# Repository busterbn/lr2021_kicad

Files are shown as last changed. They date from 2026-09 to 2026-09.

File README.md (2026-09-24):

# LR2021 868/915 MHz eval module in KiCad

KiCad 10 port of Semtech's LR2021 reference design, the 868/915 MHz evaluation module (e788v01a), converted from the original Altium project.

- `e788v01a/` KiCad project (schematic, board, design rules, symbol and footprint libraries with 3D models)
- `tools/` scripts used for the conversion

Open `e788v01a/LR2021_e788v01a_868_915_eval_module.kicad_pro` in KiCad 10 or newer.

## Verification

- Schematic and PCB connectivity match pin by pin (`tools/check.sh`). The Altium board was used as the reference.
- The board's 107 nets match the Altium PcbDoc, and footprint placement matches Semtech's pick and place file.
- Gerbers plotted from KiCad match Semtech's production Gerbers on all copper, solder mask and paste layers (`tools/gerber_diff.py`). Drill holes match in count and size.

## Notes

- Update PCB from Schematic shows no changes.
- KiCad treats references without a trailing number as unannotated, so 17 Altium designators got a "1" appended (`J7_SWD` is `J7_SWD1`, `868M` is `868M1`, `ANT_HF` is `ANT_HF1`). On the board, their reference fields are hidden and the original names are plain footprint texts at the same place, so the silkscreen is unchanged. If you rename one of these parts, edit that text too.
- The accessories sheet is a sub-sheet of the main sheet. The Altium project was flat, so labels shared by both sheets are global labels.
- `ANT_HF1` and `ANT_LF1` use a 3-pin symbol (1 signal, 2 and 3 GND). The original SMA footprint had pads 1, 2, 2; the second GND pad is now pad 3. The copper is unchanged.
- The Altium logo symbols had a hidden zero-length dummy pin without a pad. It is removed.
- Semtech's Altium design rules are in the `.kicad_pro` board setup, the netclasses and `.kicad_dru`. The RF clearance rules used Altium's auto-generated net names (`NetL*`, `NetC*`, `NetA*`). These nets are in the `RF` netclass.
- 42 vias under U1 and next to the XIAO module are not tented on the bottom side, as in the original.
- DRC still shows warnings that come from the original design: solder mask openings on Q1 that bridge nets, a small VBAT_3V3 copper island on the bottom layer, silkscreen overlaps and a few dangling track stubs.
- ERC shows off-grid warnings (Altium grid) and "power input not driven" errors from Altium pin types.
- `kicad-cli pcb drc --schematic-parity` reports "No corresponding pin" for nets without labels. This looks like a CLI issue.

## Conversion

1. KiCad: File > Import Non-KiCad Project > Altium Project, then save the schematic.
2. `make_hierarchy.py`: turns the two top-level sheets into root sheet plus sub-sheet.
3. `fix_labels.py`, `annotate_power.py`, `fix_pads.py`, `relink.py`, `netmap.py`, `fplib.py`, `export_fps.py`, `rules.py`, `fix_tenting.py`, `fix_refs.py` (then `relink.py`, `netmap.py` and `rules.py` again, since auto-generated net names follow the references), `fix_nopads.py`.
4. KiCad: Update PCB from Schematic, which only adds KiCad 10 footprint metadata and nets for unused pins.
5. After each step, `check.sh` compares schematic and PCB connectivity.

The KiCad Python scripts (`fix_pads.py`, `export_fps.py`, `fix_refs.py`, `fix_nopads.py`) run with KiCad's bundled Python. `fix_tenting.py` and `gerber_diff.py` need `olefile`, `gerbonara`, `pillow` and `numpy`.

## License

The design is Semtech's. Semtech's download contains no license terms, so ask Semtech before you publish or redistribute it. This is not an official Semtech release.

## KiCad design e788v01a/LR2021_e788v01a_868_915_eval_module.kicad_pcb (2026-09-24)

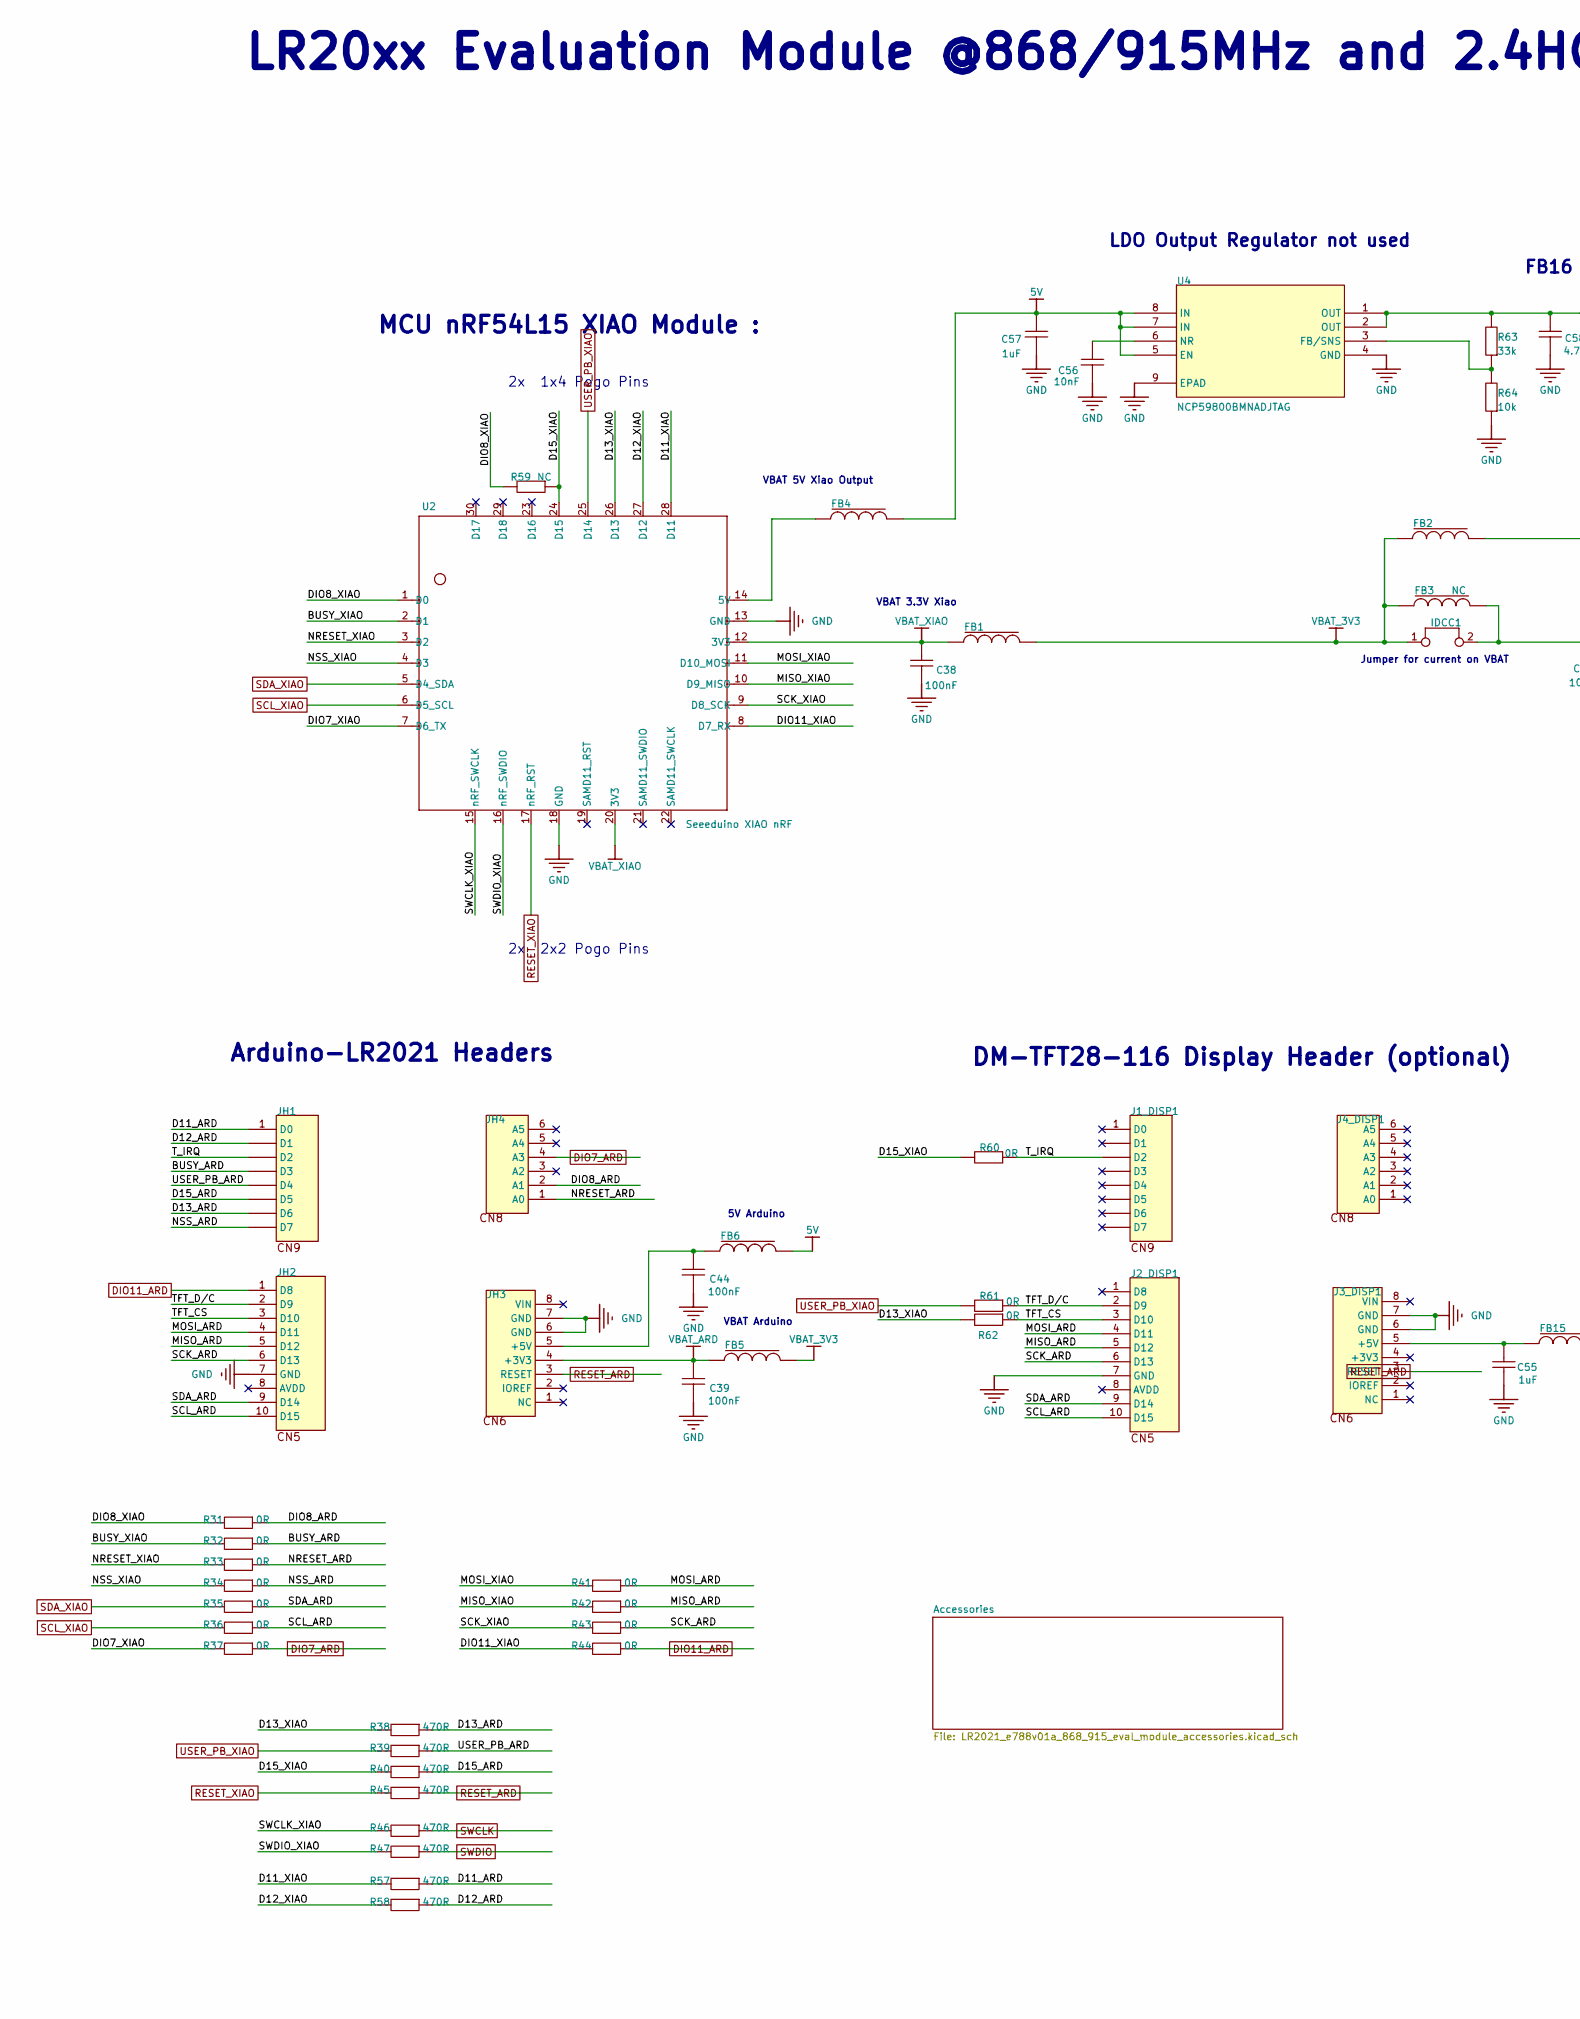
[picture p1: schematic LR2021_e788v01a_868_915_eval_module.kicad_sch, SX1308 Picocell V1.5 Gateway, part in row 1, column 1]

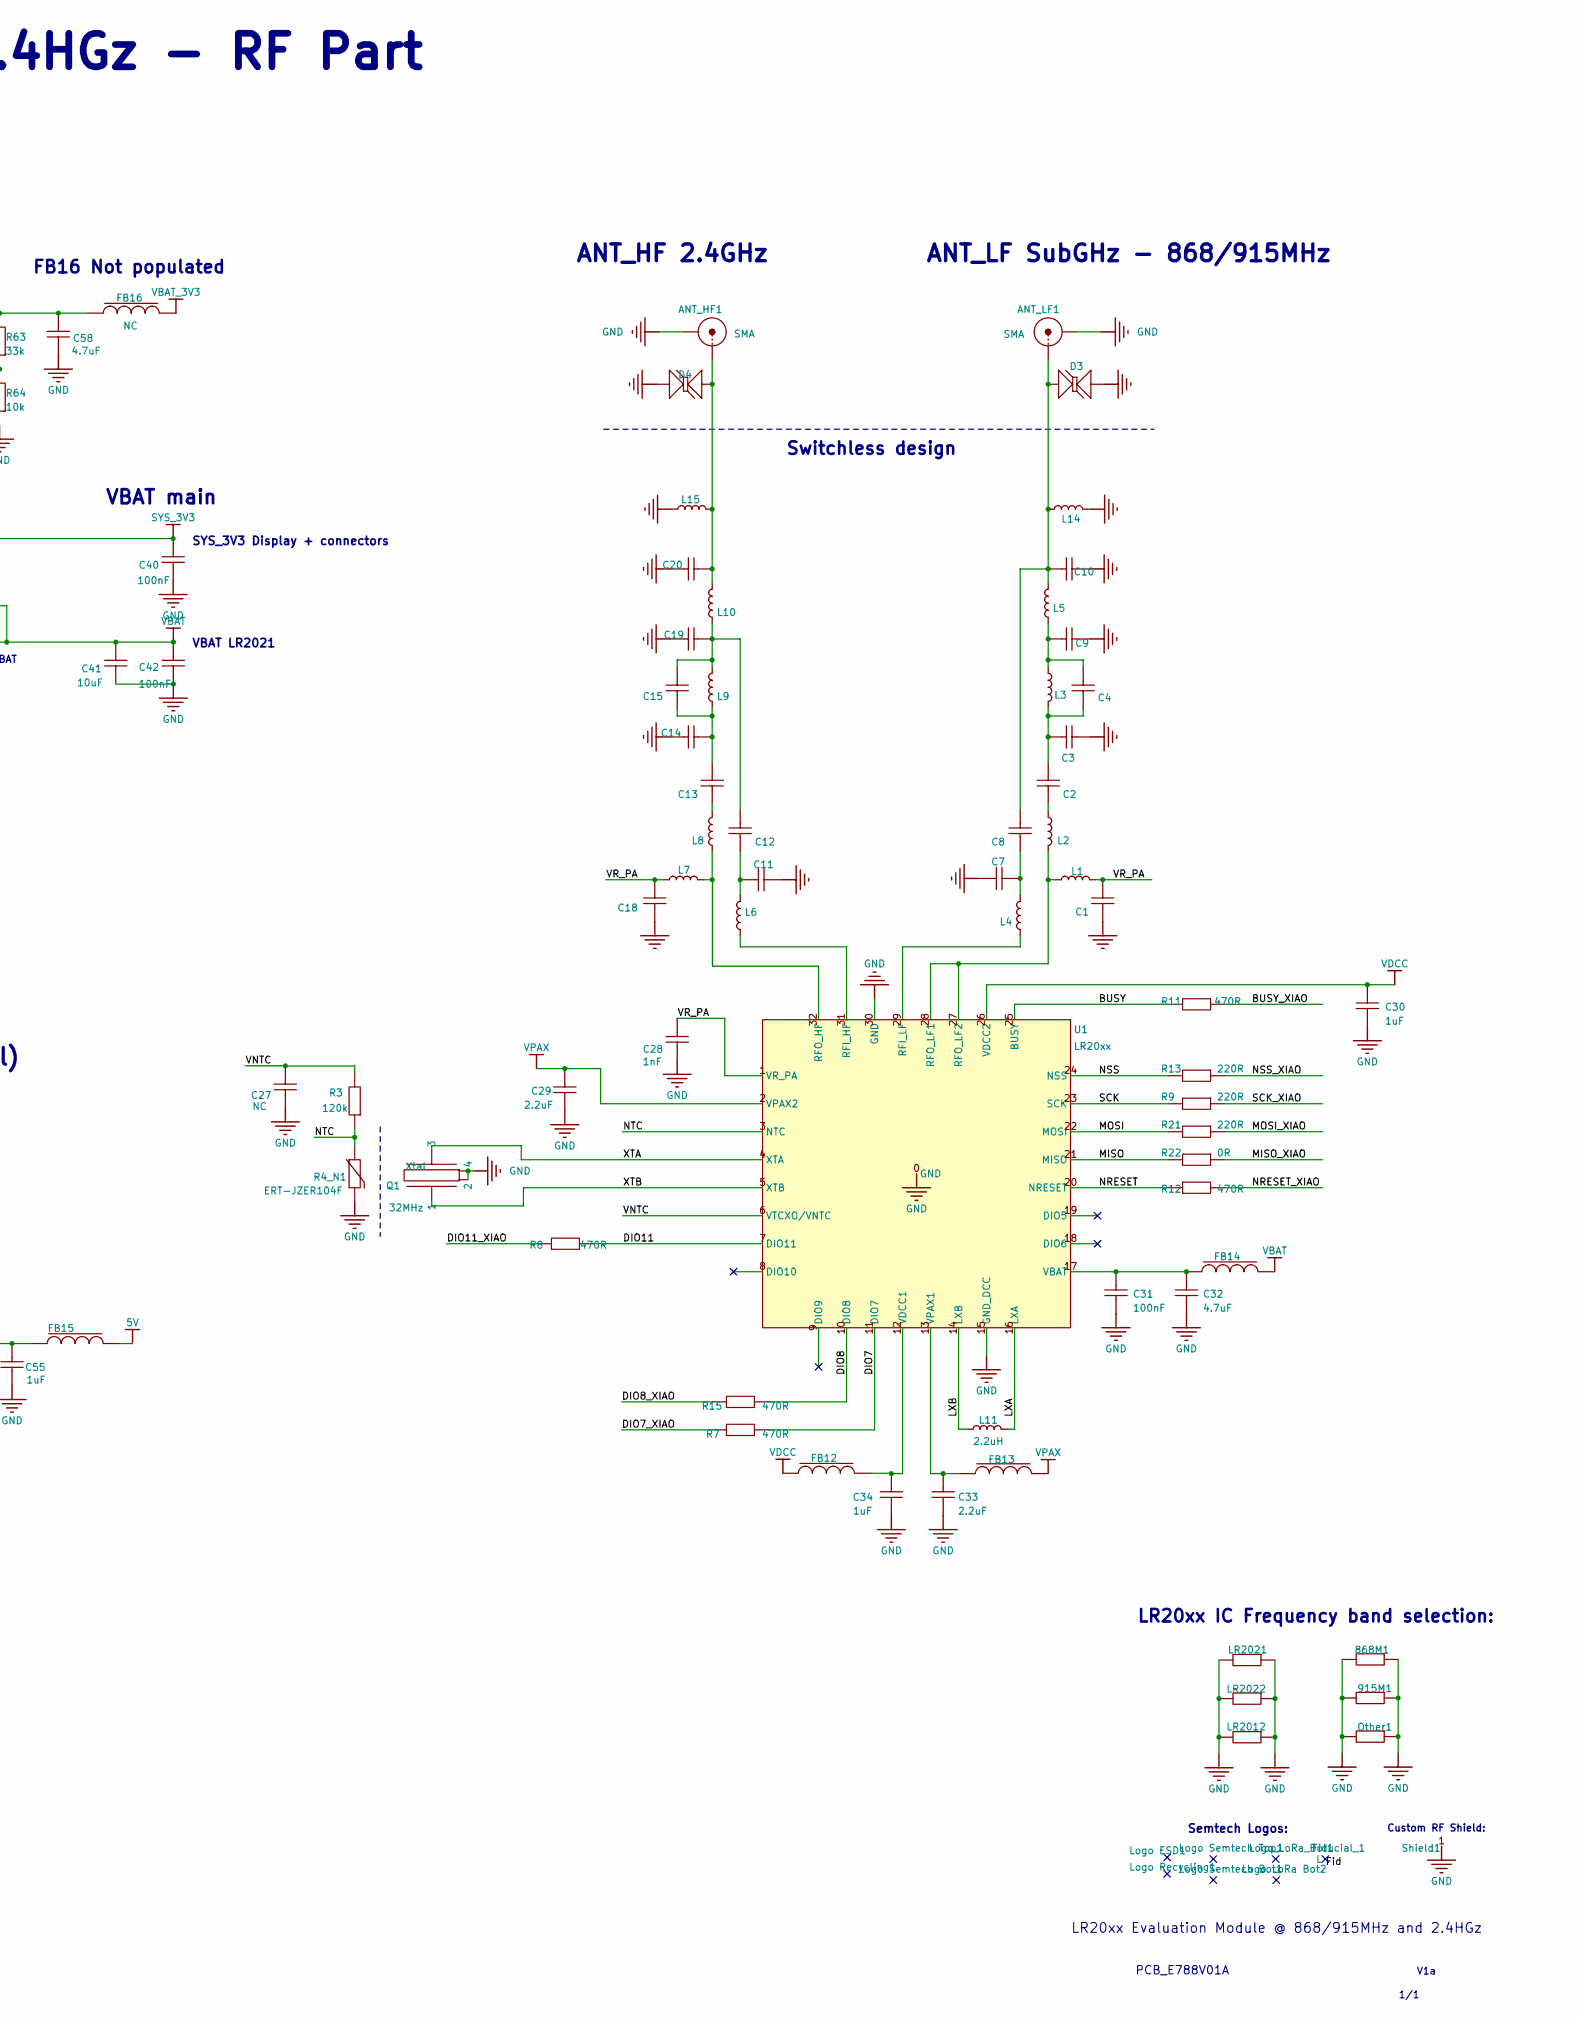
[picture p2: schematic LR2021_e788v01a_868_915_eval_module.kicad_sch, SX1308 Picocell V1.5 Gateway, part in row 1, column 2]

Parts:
868M1, 915M1: Resistor; r_201_smd
ANT_HF1: SMA; SMA_end_launch_1.2mm_6.35mm_female
ANT_LF1: SMA; SMA_end_launch_1.2mm_6.35mm_female
C1, C2, C3, C4, C7, C8, C9, C10, C11, C12, C13, C14, C15, C18, C19, C20, C27, C28, C31, C38, C39, C42, C44, C56: Cap; c_201_smd
C29, C30, C32, C33, C34, C40, C41, C55, C57, C58: Cap; c_402_smd
D3, D4: TVS Diode; SLP0603P2X3F
FB1, FB2, FB3, FB4, FB5, FB6, FB15, FB16: Ferrite beads; Ferrite_402_smd
FB12, FB13, FB14: Ferrite beads; Ferrite_201_smd
Fiducial_1: Fiducial_Mark; fiducial_mark_signal_top Small
IDCC1: Jumper; bridge_254mm
J1_DISP1, J3_DISP1: Header 8; HDR1X8
J2_DISP1: Header 10; HDR1X10
J4_DISP1: Header 6; HDR1X6
JH1: Header 8; HDR1X8 Arduino CN9
JH2: Header 10; HDR1X10 Arduino CN5
JH3: Header 8; HDR1X8 Arduino CN6
JH4: Header 6; HDR1X6 Arduino CN8
L1: Inductor symbol; lqw_402_smd
L2, L3, L5, L6, L7, L8, L9, L10, L14, L15: Inductor symbol; LQW_201_smd
L4: Inductor symbol; LQP_201_smd
L11: Inductor symbol; LQM18P_603_INDUCTOR_SMD
LR2012, LR2021, LR2022: Resistor; r_201_smd
Logo ESD1: Logo symbol; Logo ESD
Logo LoRa Bot2: Logo symbol; Logo LoRa Size4
Logo Recycling1: Logo symbol; Logo Recycling1
Logo Semtech Bot1: Logo symbol; logo_semtech_horiz_size4
Logo Semtech Top1: Logo symbol; logo_semtech_horiz_size3
Logo_LoRa_Bot1: Logo symbol; Logo LoRa Size4
Other1: Resistor; r_201_smd
Q1: Xtal; XTAL_1612
R3, R7, R8, R9, R11, R12, R13, R15, R21, R22, R31, R32, R33, R34, R35, R36, R37, R38, R39, R40, R41, R42, R43, R44, R45, R46, R47, R57, R58, R59, R60, R61, R62, R63, R64: Resistor; r_201_smd
R4_N1: NTC; r_201_smd
Shield1: RF Shield; Custom shield RD LR2021
U1: LR20xx; qfn32l_5x5mm
U2: Seeeduino XIAO nRF; MODULE14P-2.54-21X17.8MM-TEST_nRF54L15
U4: NCP59800BMNADJTAG; DFN8_3X3-0P65_506DB-A_OSI; MANUFACTURER_PART_NUMBER NCP59800BMNADJTAG

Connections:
5V: C57.2, FB4.2, FB6.2, FB15.2, U4.5 (EN), U4.7 (IN), U4.8 (IN); also elsewhere on the board
/BUSY: R11.1, U1.25 (BUSY)
/BUSY_ARD: JH1.4 (D3), R32.2
/BUSY_XIAO: R11.2, R32.1, U2.2 (D1)
/D11_ARD: JH1.1 (D0), R57.2
/D11_XIAO: R57.1, U2.28 (D11)
/D12_ARD: JH1.2 (D1), R58.2
/D12_XIAO: R58.1, U2.27 (D12)
/D13_ARD: JH1.7 (D6), R38.2
/D13_XIAO: R38.1, R62.1, U2.26 (D13)
/D15_ARD: JH1.6 (D5), R40.2
/D15_XIAO: R40.1, R59.2, R60.1, U2.24 (D15)
/DIO7: R7.1, U1.11 (DIO7)
/DIO7_XIAO: R7.2, R37.1, U2.7 (D6_TX)
/DIO8: R15.1, U1.10 (DIO8)
/DIO8_ARD: JH4.2 (A1), R31.2
/DIO8_XIAO: R15.2, R31.1, R59.1, U2.1 (D0)
/DIO11: R8.1, U1.7 (DIO11)
/DIO11_XIAO: R8.2, R44.1, U2.8 (D7_RX)
/Fid: Fiducial_1.0 (L_0)
/LXA: L11.2, U1.16 (LXA)
/LXB: L11.1, U1.14 (LXB)
/MISO: R22.1, U1.21 (MISO)
/MISO_ARD: J2_DISP1.5 (D12), JH2.5 (D12), R42.2
/MISO_XIAO: R22.2, R42.1, U2.10 (D9_MISO)
/MOSI: R21.1, U1.22 (MOSI)
/MOSI_ARD: J2_DISP1.4 (D11), JH2.4 (D11), R41.2
/MOSI_XIAO: R21.2, R41.1, U2.11 (D10_MOSI)
/NRESET: R12.2, U1.20 (NRESET)
/NRESET_ARD: JH4.1 (A0), R33.2
/NRESET_XIAO: R12.1, R33.1, U2.3 (D2)
/NSS: R13.1, U1.24 (NSS)
/NSS_ARD: JH1.8 (D7), R34.2
/NSS_XIAO: R13.2, R34.1, U2.4 (D3)
/NTC: R3.2, R4_N1.2, U1.3 (NTC)
/SCK: R9.1, U1.23 (SCK)
/SCK_ARD: J2_DISP1.6 (D13), JH2.6 (D13), R43.2
/SCK_XIAO: R9.2, R43.1, U2.9 (D8_SCK)
/SCL_ARD: J2_DISP1.10 (D15), JH2.10 (D15), R36.2
/SDA_ARD: J2_DISP1.9 (D14), JH2.9 (D14), R35.2
/SWCLK_XIAO: R46.1, U2.15 (nRF_SWCLK)
/SWDIO_XIAO: R47.1, U2.16 (nRF_SWDIO)
/TFT_CS: J2_DISP1.3 (D10), JH2.3 (D10), R62.2
/TFT_D/C: J2_DISP1.2 (D9), JH2.2 (D9), R61.2
/T_IRQ: J1_DISP1.3 (D2_3), JH1.3 (D2), R60.2
/USER_PB_ARD: JH1.5 (D4), R39.2
/VNTC: C27.2, R3.1, U1.6 (VTCXO/VNTC)
/VR_PA: C1.2, C18.2, C28.2, L1.1, L7.1, U1.1 (VR_PA)
/XTA: Q1.3, U1.4 (XTA)
/XTB: Q1.1, U1.5 (XTB)
DIO7_ARD: JH4.4 (A3), R37.2; also elsewhere on the board
DIO11_ARD: JH2.1 (D8), R44.2; also elsewhere on the board
GND: 868M1.1, 868M1.2, 915M1.1, 915M1.2, ANT_HF1.2 (GND), ANT_HF1.3 (GND), ANT_LF1.2 (GND), ANT_LF1.3 (GND), C1.1, C3.1, C7.1, C9.1, C10.1, C11.1, C14.1, C18.1, C19.1, C20.1, C27.1, C28.1, C29.1, C30.1, C31.1, C32.1, C33.1, C34.1, C38.1, C39.1, C40.1, C41.1, C42.1, C44.1, C55.1, C56.1, C57.1, C58.1, D3.1 (A), D4.1 (A), J2_DISP1.7 (GND), J3_DISP1.6 (GND), J3_DISP1.7 (GND), JH2.7 (GND), JH3.6 (GND), JH3.7 (GND), L14.2, L15.1, LR2012.1, LR2012.2, LR2021.1, LR2021.2, LR2022.1, LR2022.2, Other1.1, Other1.2, Q1.2, Q1.4, R4_N1.1, R64.2, Shield1.1 (1_1), U1.0 (GND), U1.15 (GND_DCC), U1.30 (GND), U2.13 (GND), U2.18 (GND), U4.4 (GND), U4.9 (EPAD); also elsewhere on the board
unnamed: ANT_HF1.1 (Signal), C20.2, D4.2 (K), L10.2, L15.2
unnamed: ANT_LF1.1 (Signal), C8.2, C10.2, D3.2 (K), L5.2, L14.1
unnamed: C2.1, L2.2
unnamed: C2.2, C3.2, C4.1, L3.1
unnamed: C4.2, C9.2, L3.2, L5.1
unnamed: C7.2, C8.1, L4.2
unnamed: C11.2, C12.1, L6.1
unnamed: C12.2, C15.2, C19.2, L9.2, L10.1
unnamed: C13.1, L8.2
unnamed: C13.2, C14.2, C15.1, L9.1
unnamed: C58.2, FB16.1, R63.1, U4.1 (OUT), U4.2 (OUT)
unnamed: C55.2, FB15.1, J3_DISP1.5 (+5V)
unnamed: C44.2, FB6.1, JH3.5 (+5V)
unnamed: L6.2, U1.31 (RFI_HF)
unnamed: L4.1, U1.29 (RFI_LF)
unnamed: L7.2, L8.1, U1.32 (RFO_HF)
unnamed: L1.2, L2.1, U1.27 (RFO_LF2), U1.28 (RFO_LF1)
unnamed: C31.2, C32.2, FB14.1, U1.17 (VBAT)
unnamed: C34.2, FB12.2, U1.12 (VDCC1)
unnamed: C33.2, FB13.1, U1.13 (VPAX1)
unnamed: FB4.1, U2.14 (5V)
unnamed: R63.2, R64.1, U4.3 (FB/SNS)
unnamed: C56.2, U4.6 (NR)
RESET_ARD: J3_DISP1.3 (RESET), JH3.3 (RESET), R45.2; also elsewhere on the board
RESET_XIAO: R45.1, U2.17 (nRF_RST); also elsewhere on the board
SCL_XIAO: R36.1, U2.6 (D5_SCL); also elsewhere on the board
SDA_XIAO: R35.1, U2.5 (D4_SDA); also elsewhere on the board
SWCLK: R46.2; also elsewhere on the board
SWDIO: R47.2; also elsewhere on the board
SYS_3V3: C40.2, FB2.2; also elsewhere on the board
USER_PB_XIAO: R39.1, R61.1, U2.25 (D14); also elsewhere on the board
VBAT: C41.2, C42.2, FB3.2, FB14.2, IDCC1.2
VBAT_3V3: FB1.2, FB2.1, FB3.1, FB5.2, FB16.2, IDCC1.1
VBAT_ARD: C39.2, FB5.1, JH3.4 (+3V3)
VBAT_XIAO: C38.2, FB1.1, U2.12 (3V3), U2.20 (3V3)
VDCC: C30.2, FB12.1, U1.26 (VDCC2)
VPAX: C29.2, FB13.2, U1.2 (VPAX2)

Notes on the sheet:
VBAT Arduino
MCU nRF54L15 XIAO Module :
LR20xx IC Frequency band selection:
SYS_3V3 Display + connectors
PCB_E788V01A
VBAT main
LR20xx Evaluation Module @ 868/915MHz and 2.4HGz
5V Arduino
V1a
ANT_HF 2.4GHz
ANT_LF SubGHz - 868/915MHz
LDO Output Regulator not used
Jumper for current on VBAT
VBAT 3.3V Xiao
LR20xx Evaluation Module @868/915MHz and 2.4HGz - RF Part
VBAT LR2021
FB16 Not populated
Arduino-LR2021 Headers
VBAT 5V Xiao Output
Switchless design
1/1
2x 2x2 Pogo Pins
Custom RF Shield:
2x 1x4 Pogo Pins
DM-TFT28-116 Display Header (optional)
Semtech Logos:

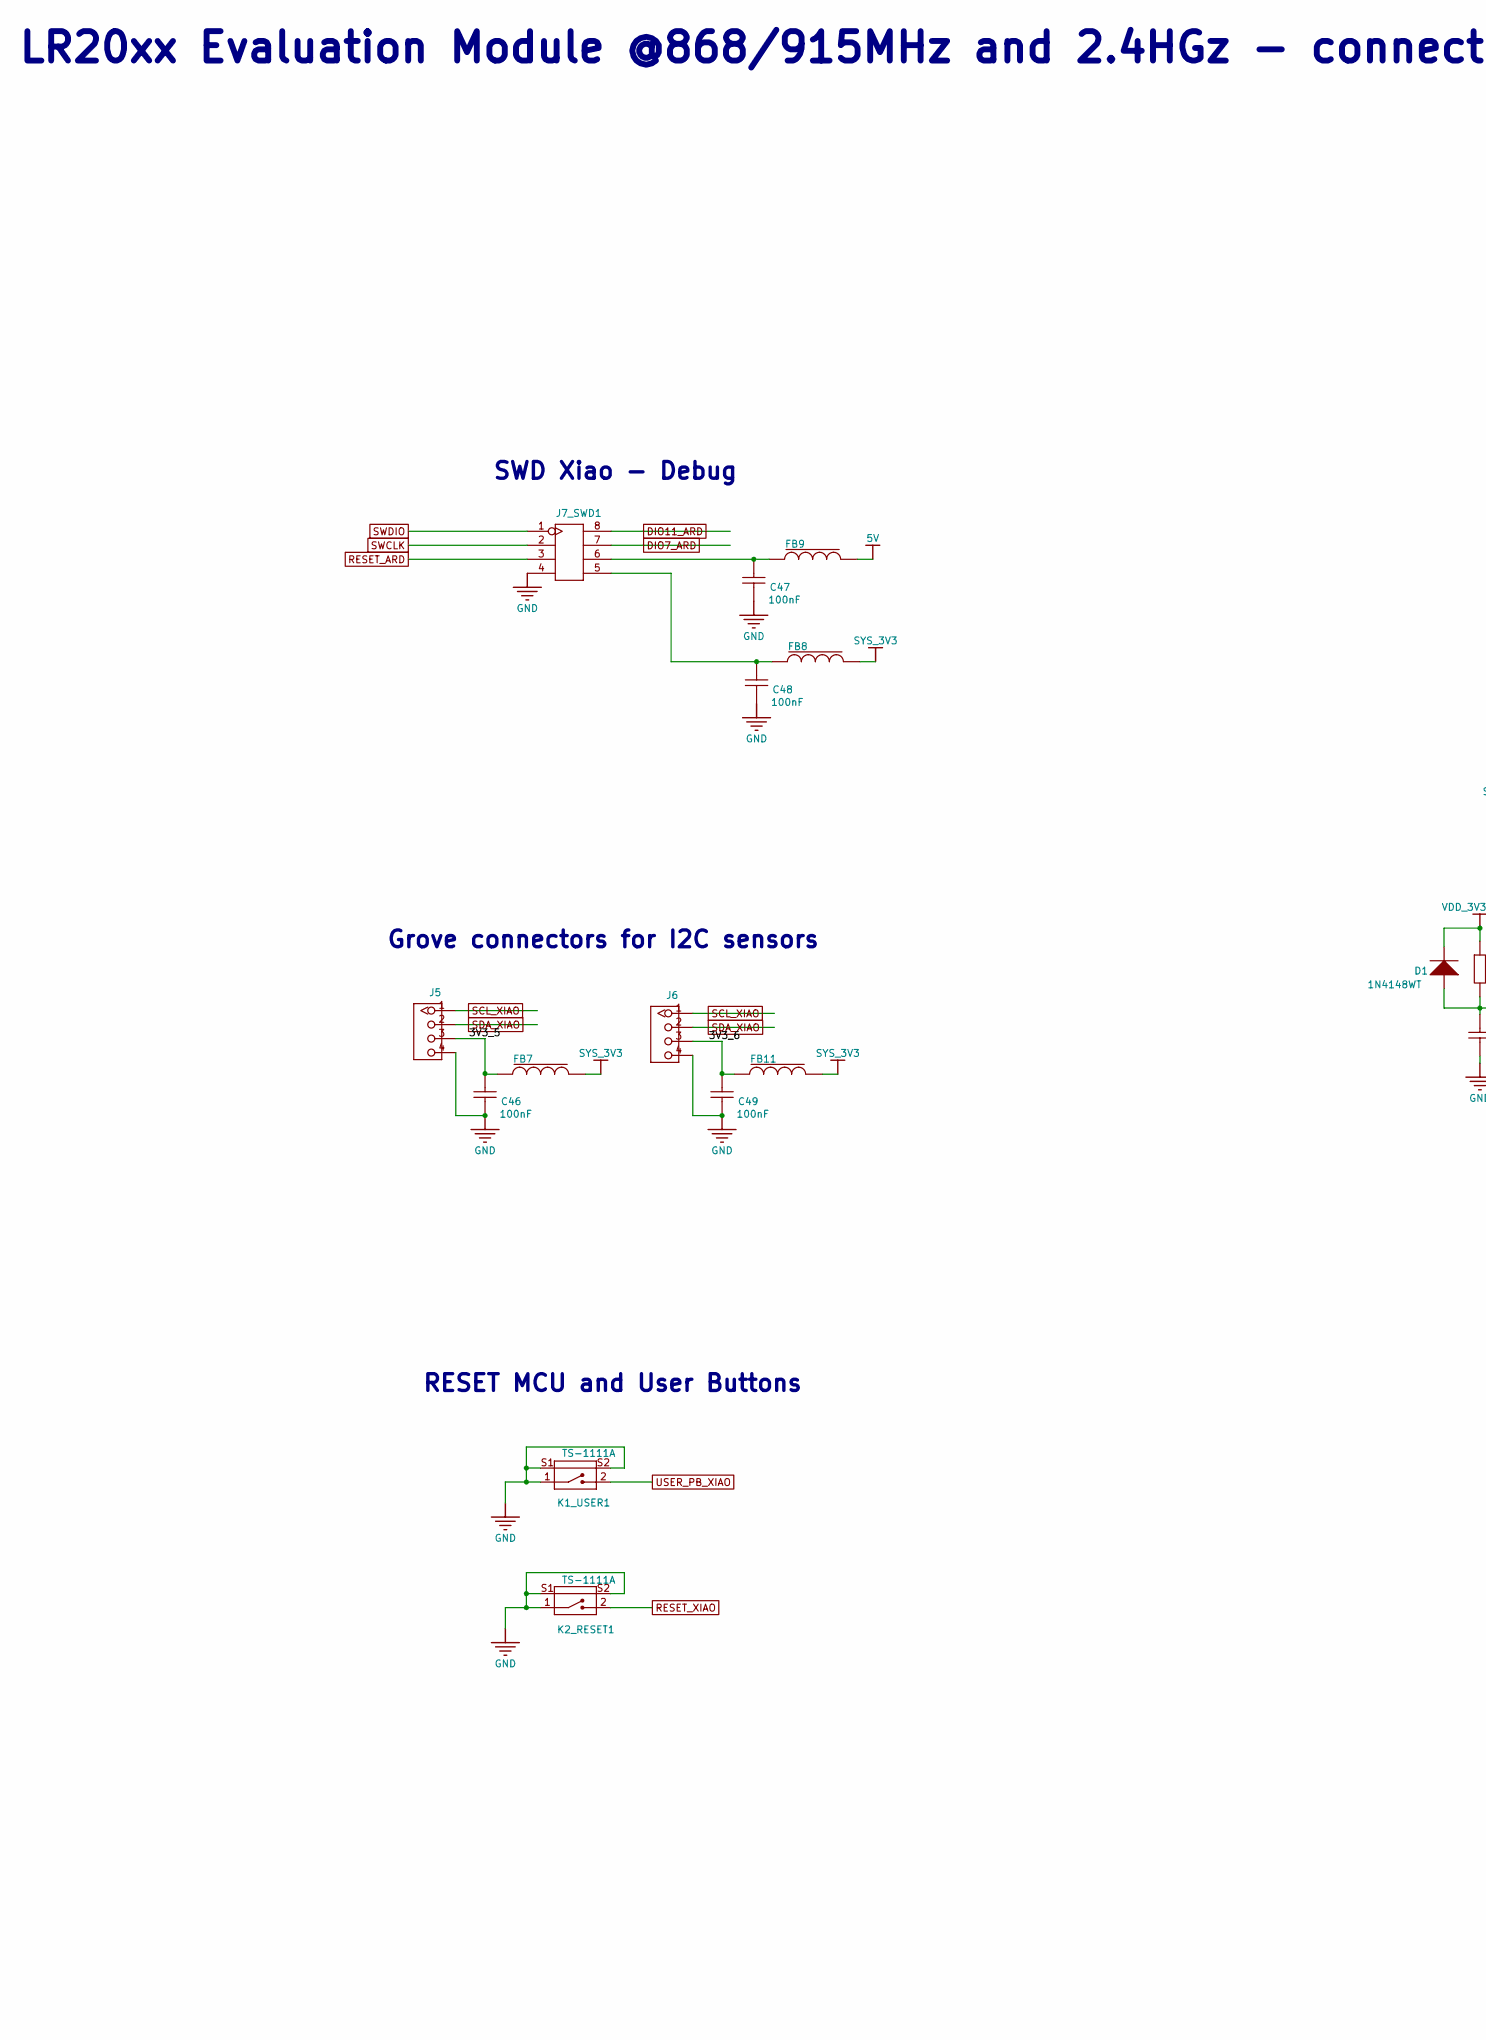
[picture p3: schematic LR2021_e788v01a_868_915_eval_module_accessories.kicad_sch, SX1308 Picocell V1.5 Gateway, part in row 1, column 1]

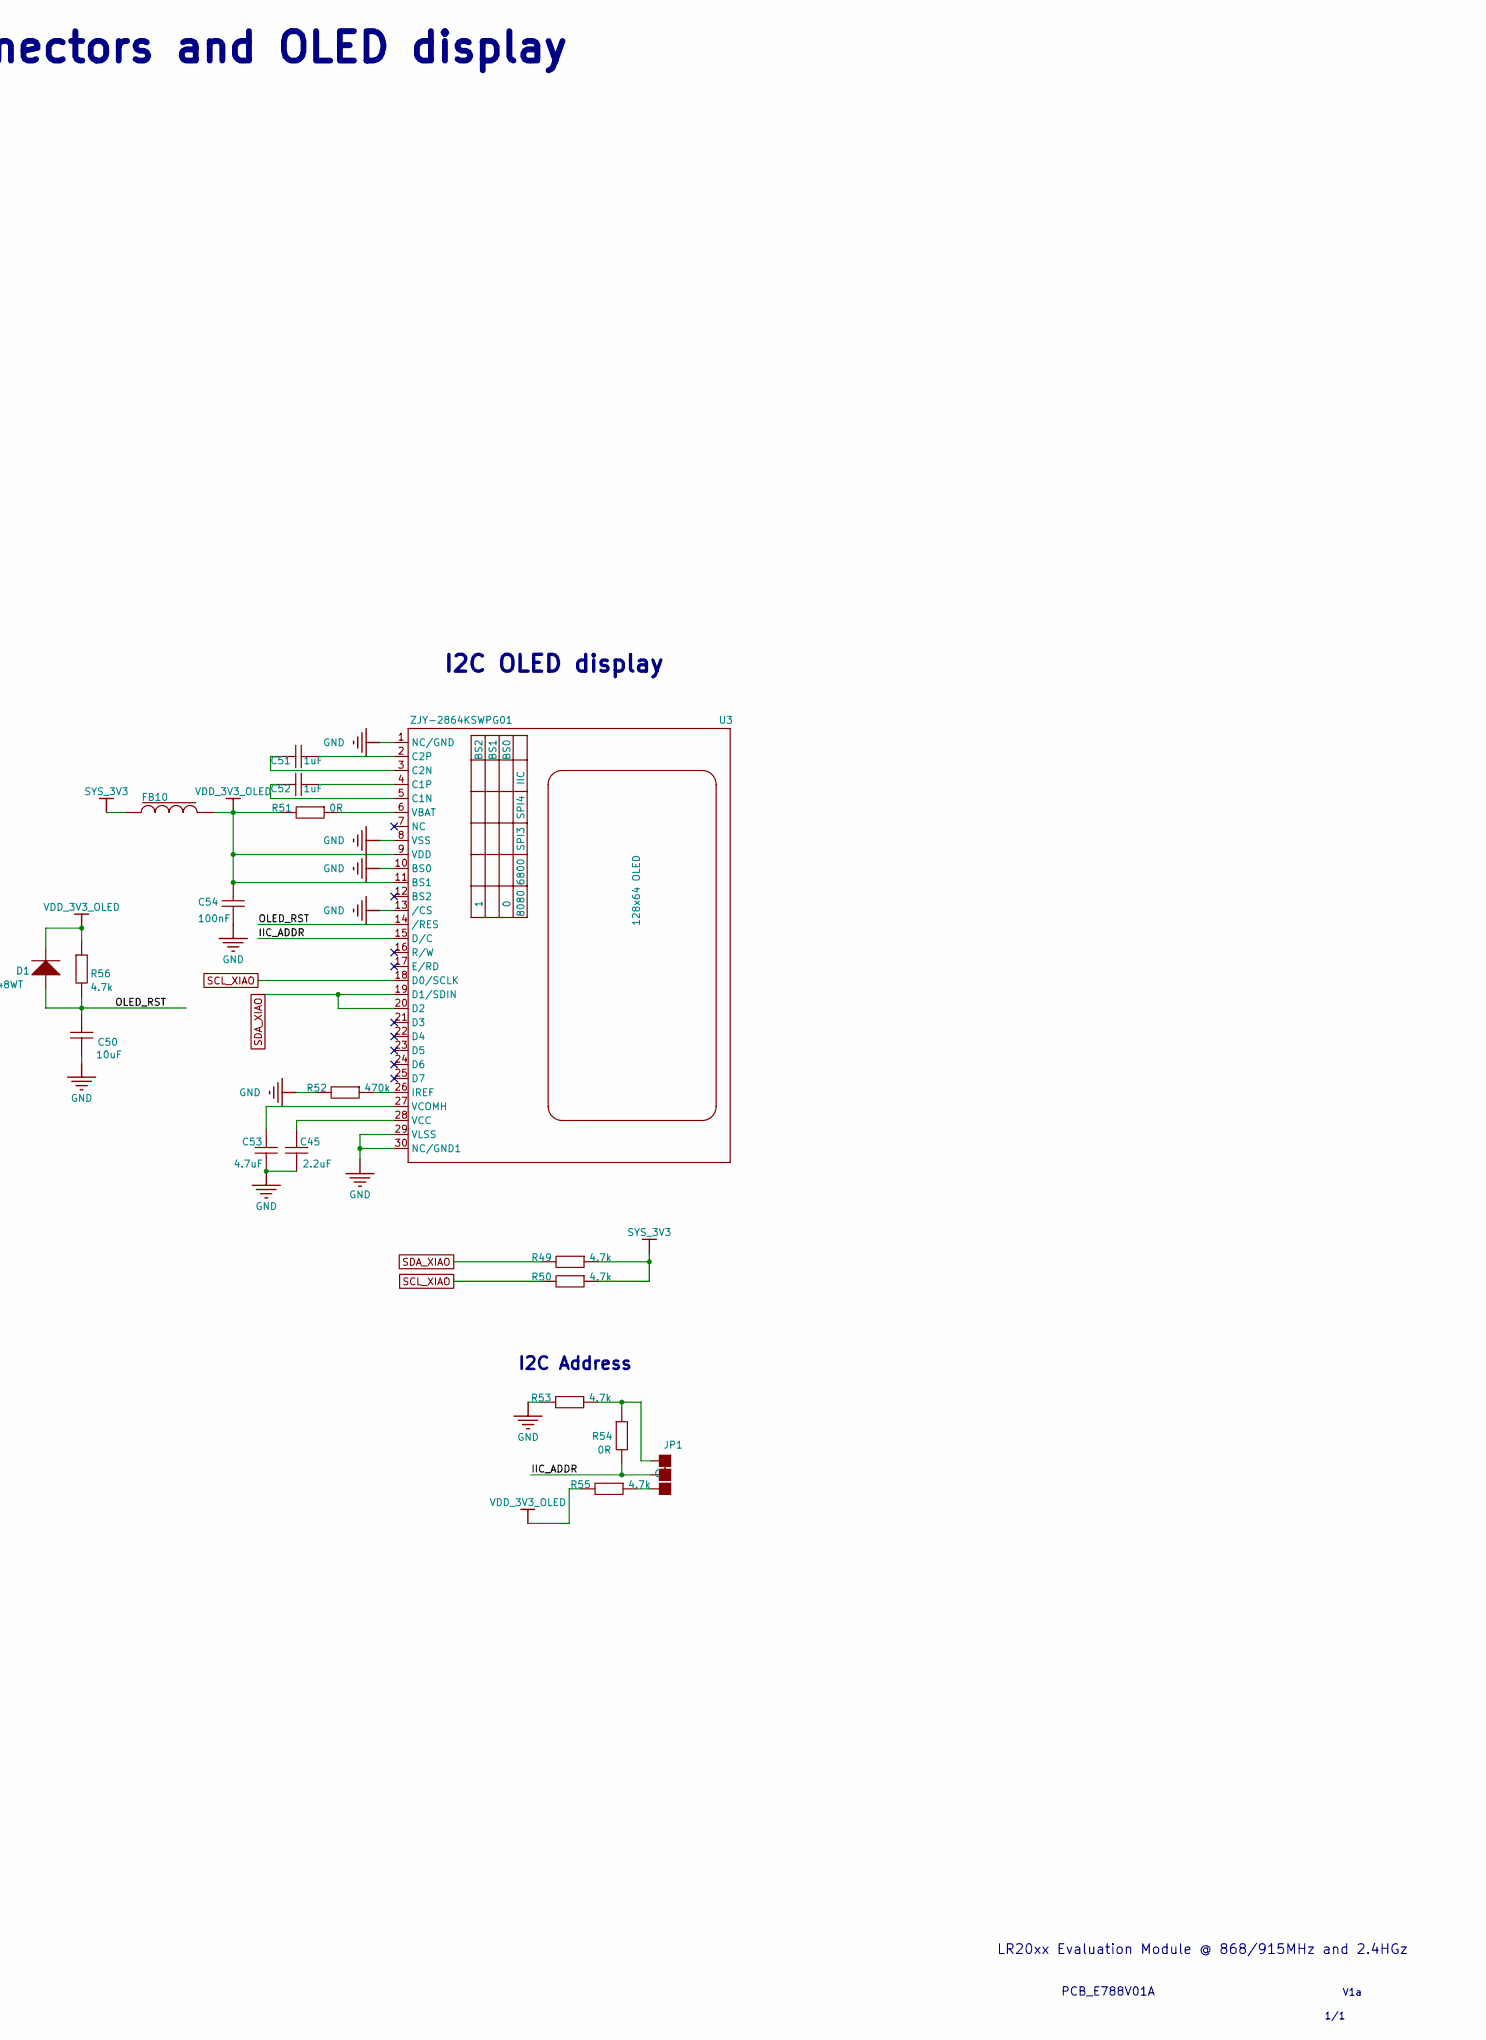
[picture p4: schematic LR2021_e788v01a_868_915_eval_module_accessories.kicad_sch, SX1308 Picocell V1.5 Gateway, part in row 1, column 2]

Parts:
C45, C50, C51, C52, C53: Cap; c_402_smd
C46, C47, C48, C49, C54: Cap; c_201_smd
D1: 1N4148WT; SOD-523
FB7, FB8, FB9, FB11: Ferrite beads; Ferrite_201_smd
FB10: Ferrite beads; Ferrite_402_smd
J5, J6: GROVE-CONNECTOR-DIP-320110034; HW4-2.0-00D
J7_SWD1: HEADER-2X4P-2.54-SMD; H2X4-SMD-2.54
JP1: JP-3P-SHORT; 3P-SMD-SHORT
K1_USER1, K2_RESET1: TS-1111A; SW4-SMD-4.5X3.8X1.8MM-90D
R49, R50: Resistor; r_201_smd
R51, R52, R53, R54, R55, R56: Resistor; r_402_smd
U3: ZJY-2864KSWPG01; OLED30P-0.7-24.74X16.9MM

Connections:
5V: FB9.2; also elsewhere on the board
/Accessories/3V3_5: C46.2, FB7.1, J5.3
/Accessories/3V3_6: C49.2, FB11.1, J6.3
/Accessories/IIC_ADDR: JP1.MM (C), R54.1, U3.15 (D/C)
/Accessories/OLED_RST: C50.2, D1.1 (A), R56.1, U3.14 (/RES)
DIO7_ARD: J7_SWD1.7; also elsewhere on the board
DIO11_ARD: J7_SWD1.8; also elsewhere on the board
GND: C45.2, C46.1, C47.1, C48.1, C49.1, C50.1, C53.2, C54.2, J5.4, J6.4, J7_SWD1.4, K1_USER1.1, K1_USER1.S1, K1_USER1.S2, K2_RESET1.1, K2_RESET1.S1, K2_RESET1.S2, R52.1, R53.1, U3.1 (NC/GND), U3.8 (VSS), U3.10 (BS0), U3.13 (/CS), U3.29 (VLSS), U3.30 (NC/GND1); also elsewhere on the board
unnamed: C47.2, FB9.1, J7_SWD1.6
unnamed: C48.2, FB8.1, J7_SWD1.5
unnamed: JP1.11 (L), R53.2, R54.2
unnamed: JP1.00 (R), R55.2
unnamed: C52.2, U3.5 (C1N)
unnamed: C52.1, U3.4 (C1P)
unnamed: C51.2, U3.3 (C2N)
unnamed: C51.1, U3.2 (C2P)
unnamed: R52.2, U3.26 (IREF)
unnamed: R51.2, U3.6 (VBAT)
unnamed: C45.1, U3.28 (VCC)
unnamed: C53.1, U3.27 (VCOMH)
RESET_ARD: J7_SWD1.3; also elsewhere on the board
RESET_XIAO: K2_RESET1.2; also elsewhere on the board
SCL_XIAO: J5.1, J6.1, R50.1, U3.18 (D0/SCLK); also elsewhere on the board
SDA_XIAO: J5.2, J6.2, R49.1, U3.19 (D1/SDIN), U3.20 (D2); also elsewhere on the board
SWCLK: J7_SWD1.2; also elsewhere on the board
SWDIO: J7_SWD1.1; also elsewhere on the board
SYS_3V3: FB7.2, FB8.2, FB10.1, FB11.2, R49.2, R50.2; also elsewhere on the board
USER_PB_XIAO: K1_USER1.2; also elsewhere on the board
VDD_3V3_OLED: C54.1, D1.2 (K), FB10.2, R51.1, R55.1, R56.2, U3.9 (VDD), U3.11 (BS1)

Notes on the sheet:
1/1
LR20xx Evaluation Module @868/915MHz and 2.4HGz - connectors and OLED display
I2C Address
V1a
LR20xx Evaluation Module @ 868/915MHz and 2.4HGz
RESET MCU and User Buttons
Grove connectors for I2C sensors
I2C OLED display
PCB_E788V01A
SWD Xiao - Debug

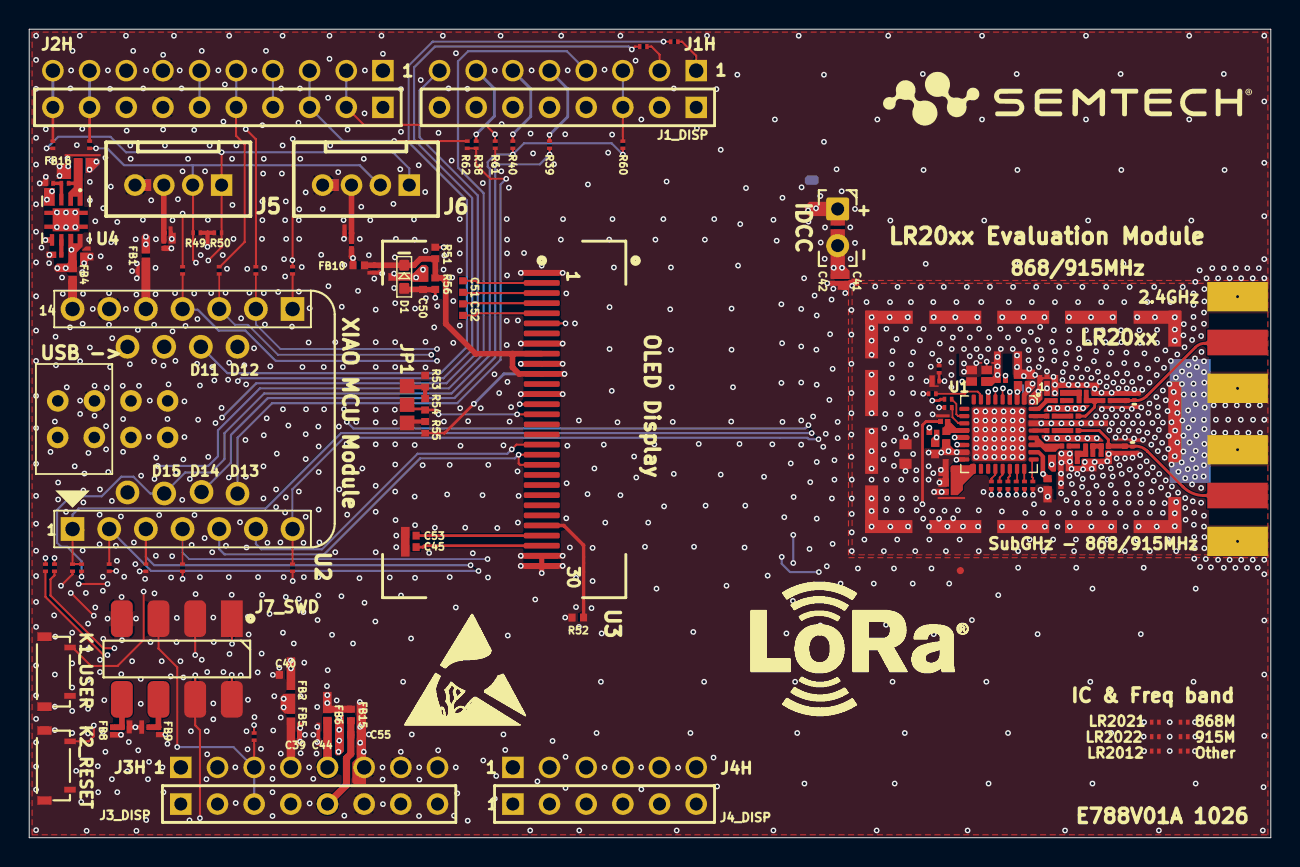
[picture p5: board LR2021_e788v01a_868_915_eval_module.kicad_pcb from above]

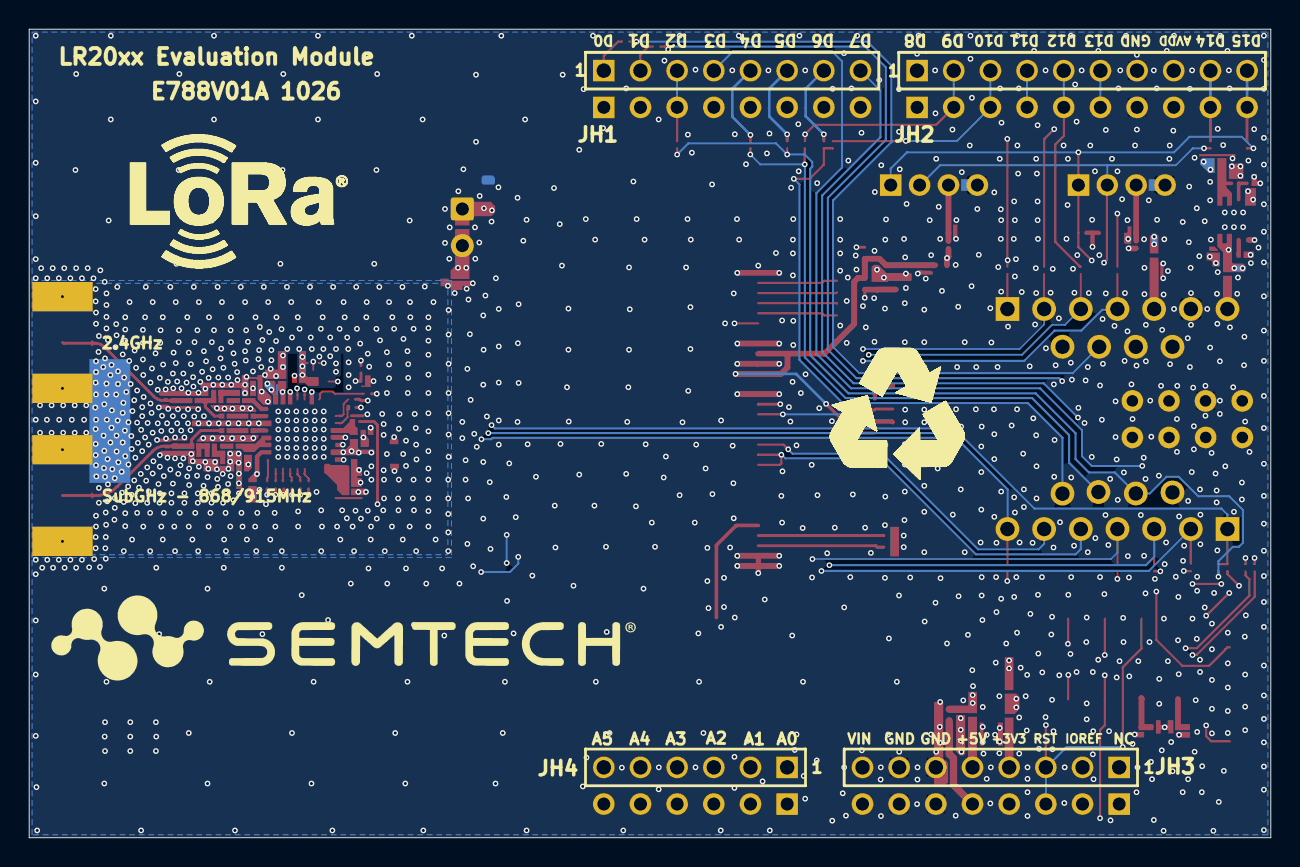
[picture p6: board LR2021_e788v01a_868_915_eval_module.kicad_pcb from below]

Board: 4 copper layers, 86.0 x 56.0 mm, 156 parts (7 on the bottom side), 106 nets.

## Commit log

2026-09-24 Added altium to kicad port
    [LR2021_e788v01a_868_915_eval_module.kicad_pcb, LR2021_e788v01a_868_915_eval_module.kicad_sch, LR2021_e788v01a_868_915_eval_module_accessories.kicad_sch]
2026-09-24 Fixed warnings
    [LR2021_e788v01a_868_915_eval_module.kicad_pcb, LR2021_e788v01a_868_915_eval_module.kicad_sch, LR2021_e788v01a_868_915_eval_module_accessories.kicad_sch]

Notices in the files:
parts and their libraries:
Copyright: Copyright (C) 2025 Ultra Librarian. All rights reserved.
